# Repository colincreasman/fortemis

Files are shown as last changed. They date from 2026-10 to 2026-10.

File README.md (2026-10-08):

# Fortemis ZMK Config

ZMK config for the Fortemis keyboard (Forager+Totem+FerrisSweep)

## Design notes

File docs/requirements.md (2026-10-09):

# Fortemis: goals and requirements

Fortemis is a low-profile, wireless, split keyboard designed from scratch. It combines three boards
the owner already uses:

| Source board | What Fortemis takes from it |
|---|---|
| **Ferris Sweep** (Bling LP build by keebmaker) | Column layout: a tiny footprint and the steep column stagger, especially on the pinky |
| **TOTEM** by GEIST (and **Totemist**, ErgoMech's closed-source 36-key derivative) | Column splay angles only |
| **Forager** by carrefinho (sold by PandaKB) | Thumb-cluster placement and **everything else**: enclosed case, how the controller and battery are fitted, reset access, size, sturdiness, weight |

The name combines **For**ager, **Tem** (TOTEM/Totemist) and Ferr**is**.

This file records what the owner asked for. How each requirement is being met, and the decisions
behind that, are in [design-log.md](design-log.md).

## 1. Background

- The Ferris Sweep is the owner's favorite keyboard, because of its tiny footprint and the steep
  stagger on the pinky column.
- The owner's hands sweat a lot (hyperhidrosis). On the plateless Sweep, moisture has caused dead
  keys and switches keep falling out. The Forager's fully enclosed two-piece case has had neither
  problem: the top plate holds every switch in place, and the board is sealed in.
- The owner can easily press the Forager's reset button through a small print-in-place tab in the
  bottom case, and likes its size, sturdiness and light weight.
- The owner does not like the controller and battery arrangement on the Sweep or the TOTEM, or the
  loose wires visible on their current Sweep.
- The owner already has a few Seeed XIAO nRF52840 boards, the controller used in the Forager and
  TOTEM.
- All three of the owner's boards run ZMK with nearly the same keymap: QWERTY with home-row mods,
  and thumb keys Enter | Shift-Tab | NUM-Space | Backspace.

## 2. Tooling and deliverables

| ID | Requirement | Priority |
|---|---|---|
| T1 | Design the board with the free, open-source, beginner-friendly keyboard PCB tool from Ben Vallack's video. That tool is **Ergogen** ([video](https://www.youtube.com/watch?v=M_VuXVErD6E)). | MUST |
| T2 | Produce PCB design files (KiCad), case **STL** files, and everything else needed to build the board from scratch: fabrication outputs, parts list, firmware and build instructions. | MUST |
| T3 | Keep everything in this repository. | MUST |
| T4 | Write down the goals and requirements (this file), and keep a running record of the design process as work goes on ([design-log.md](design-log.md)). | MUST |

## 3. Layout

| ID | Requirement | Priority |
|---|---|---|
| L1 | **Column stagger** is the same as the Ferris Sweep's. | MUST |
| L1b | Make the stagger of the **4th and 5th columns** 10–20 % steeper, without straying far from the Sweep. | BONUS |
| L2 | **Column splay** uses the TOTEM's horizontal splay angles for each column, and nothing else. The stagger still follows L1. Owner's description: "barely perceptible between the first/second/third columns, getting wider toward the pinky column". | MUST |
| L3 | **Thumb cluster** has the same position (distance and angle) relative to the rest of the keyboard as the Forager's. | MUST |
| L4 | 34 keys: 3×5 plus 2 thumbs per half. Adding a 3rd thumb key per half (36 keys) is a bonus, but only if it doesn't enlarge the footprint or add PCB requirements. "Don't sweat it." | MUST (34) / BONUS (36) |
| L5 | Keys are as close together as **Choc keycaps** allow (Choc spacing). Fitting MX keycaps is not a goal. | MUST |

## 4. Electronics

| ID | Requirement | Priority |
|---|---|---|
| E1 | The controller is a **Seeed XIAO nRF52840**, like the Forager and TOTEM. It may be soldered straight to the PCB; no socket is needed. | SHOULD (preference) |
| E2 | **Wireless**, with a battery in each half. Copy how the Forager fits its XIAO and battery. | MUST |
| E3 | **Hot-swap sockets** for Kailh **Choc v1** switches. | MUST |
| E3b | Also accept **Choc v2** switches, as the Toucan2 does. | BONUS (big) |
| E4 | **Diodeless** like the Sweep is strongly wanted. If only a nice!nano can do diodeless, and only at 34 keys, use the nice!nano with 2 thumb keys per half. The exception is if that would break the Forager case's physical dimensions, which take priority. | SHOULD (strong) |
| E5 | A **power switch** and a **reset switch** on **each half**. The power switch must not be tiny like the Sweep's. TOTEM-sized switches are acceptable. | MUST |

## 5. Case and looks

| ID | Requirement | Priority |
|---|---|---|
| C1 | The case and everything else follow the **Forager**: a fully enclosed two-piece case, a top plate that holds the switches, reset access through a tab in the bottom case, the same size class, sturdy and light. | MUST (top priority) |
| C2 | No loose wires visible from outside. Everything sits inside the case, as on the Forager. | MUST |
| C3 | If the PCB makes any Forager feature impossible, **stop and tell the owner** so they can decide. | MUST (process) |

## 6. How ambiguous points were read

These readings were made without asking the owner. Each one is a single setting in the design, so
it is easy to change.

1. **"4th and 5th column" means the ring and pinky columns.** The owner numbered the TOTEM's columns
   from the inner side ("first/second/third … toward the pinky"). Counting that way also matches
   finger numbering (ring = 4, pinky = 5) and the owner's liking for a steep pinky stagger.
2. **Totemist splay means TOTEM splay.** Totemist has no public hardware files, and the owner said
   to use TOTEM. TOTEM's PCB has the inner, index and middle columns exactly parallel (0°), the
   ring column at 4° and the pinky column at 10°. The "barely perceptible" angle the owner sees is
   the ring column's 4°.
3. **Forager power switch.** The Forager has no power switch. It relies on ZMK's sleep mode, and its
   reset is the XIAO's own button pressed through the case lever. E5 is met by adding a power
   switch that is large enough to use with a finger, and by keeping the Forager's reset lever.
4. **Thumb position relative to the keyboard** is measured from the bottom key of the inner index
   column, the nearest key. That keeps the same gap and angle between the thumbs and the main keys
   as on the Forager.

## 7. Acceptance criteria

- The Ergogen config in `ergogen/` regenerates the layout, outlines and PCB.
- Layout: stagger matches the Sweep, with L1b applied to ring and pinky. Column angles are
  0/0/0/4/10° from the inner column outward. Thumbs sit relative to the inner column exactly as on
  the Forager. No Choc keycaps (17.5 × 16.5 mm) overlap.
- PCB: routed, passes KiCad DRC with no errors, and has Gerber, drill, BOM and placement outputs
  ready for ordering. Choc v1 hot-swap is required and v2 is supported if possible. Diodeless if
  possible. Power switch on each half. Reset reachable as on the Forager.
- Case: two-piece enclosed STL per half (top plate and base), built to the Forager's dimensions
  (8.4 mm stack, 2.2 mm top plate, 6.2 mm base). It includes the USB-C opening, reset lever, LED
  light pipe, power-switch opening and screw bosses, with no wires showing.
- Docs: parts list with links, build guide, and firmware (ZMK shield) for the chosen controller.

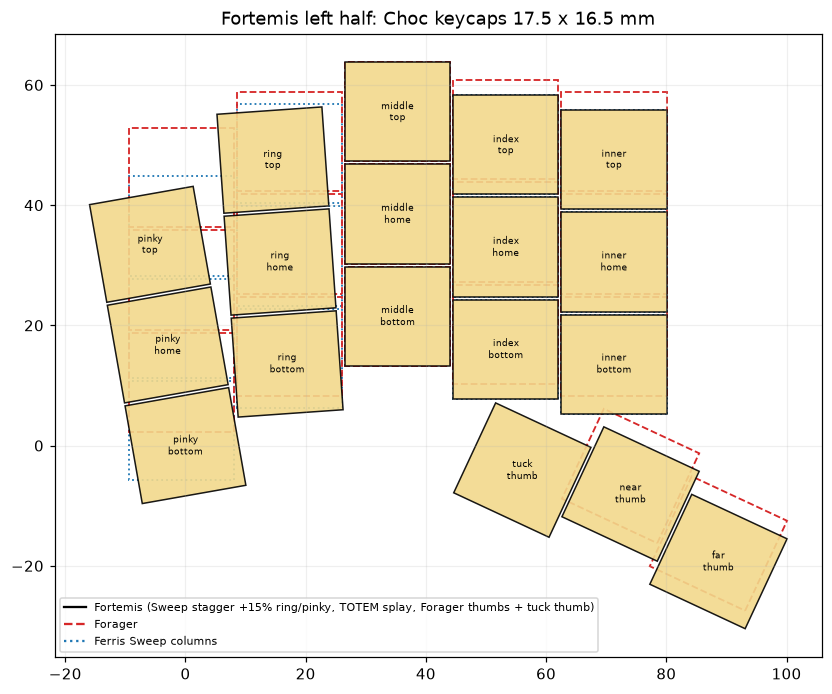
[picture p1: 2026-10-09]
docs/img/layout_compare.png

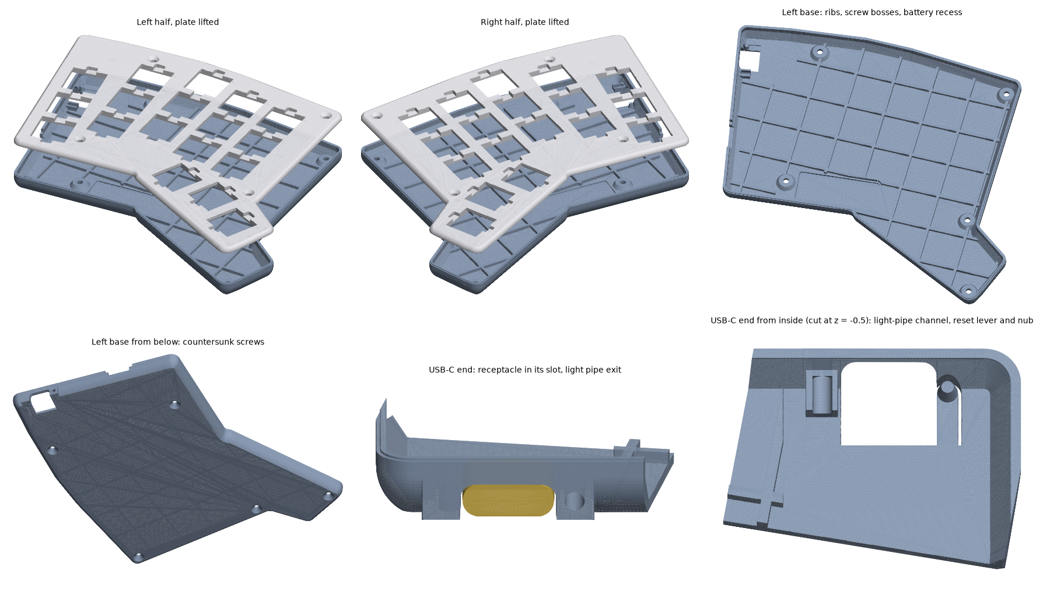
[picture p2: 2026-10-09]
docs/img/case.png

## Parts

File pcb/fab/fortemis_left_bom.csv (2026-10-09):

Comment | Designator | Footprint | LCSC Part #
Kailh Choc v1 hot-swap socket | S1,S2,S3,S4,S5,S6,S7,S8,S9,S10,S11,S12,S13,S14,S15,S16,S17,S18 | CPG135001S30 | C5333465
M2 SMD nut, 2 mm | NUT1,NUT2,NUT3,NUT4,NUT5 | SMTSO2020MTJ | C2916384
SPDT slide switch | PWR1 | MSK12C02 | C431540

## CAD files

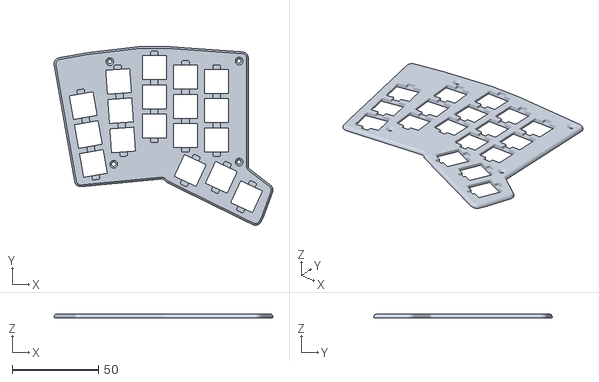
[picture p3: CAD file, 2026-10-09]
case/fortemis_left_top.stl
126.8 x 103.4 x 2.20

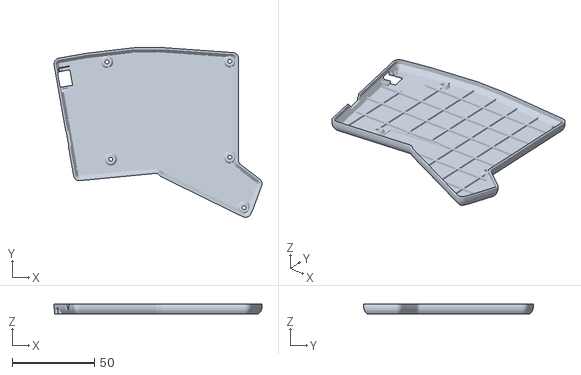
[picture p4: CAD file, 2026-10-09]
case/fortemis_left_base.stl
126.8 x 103.4 x 6.20

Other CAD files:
case/fortemis_right_top.stl
case/fortemis_right_base.stl

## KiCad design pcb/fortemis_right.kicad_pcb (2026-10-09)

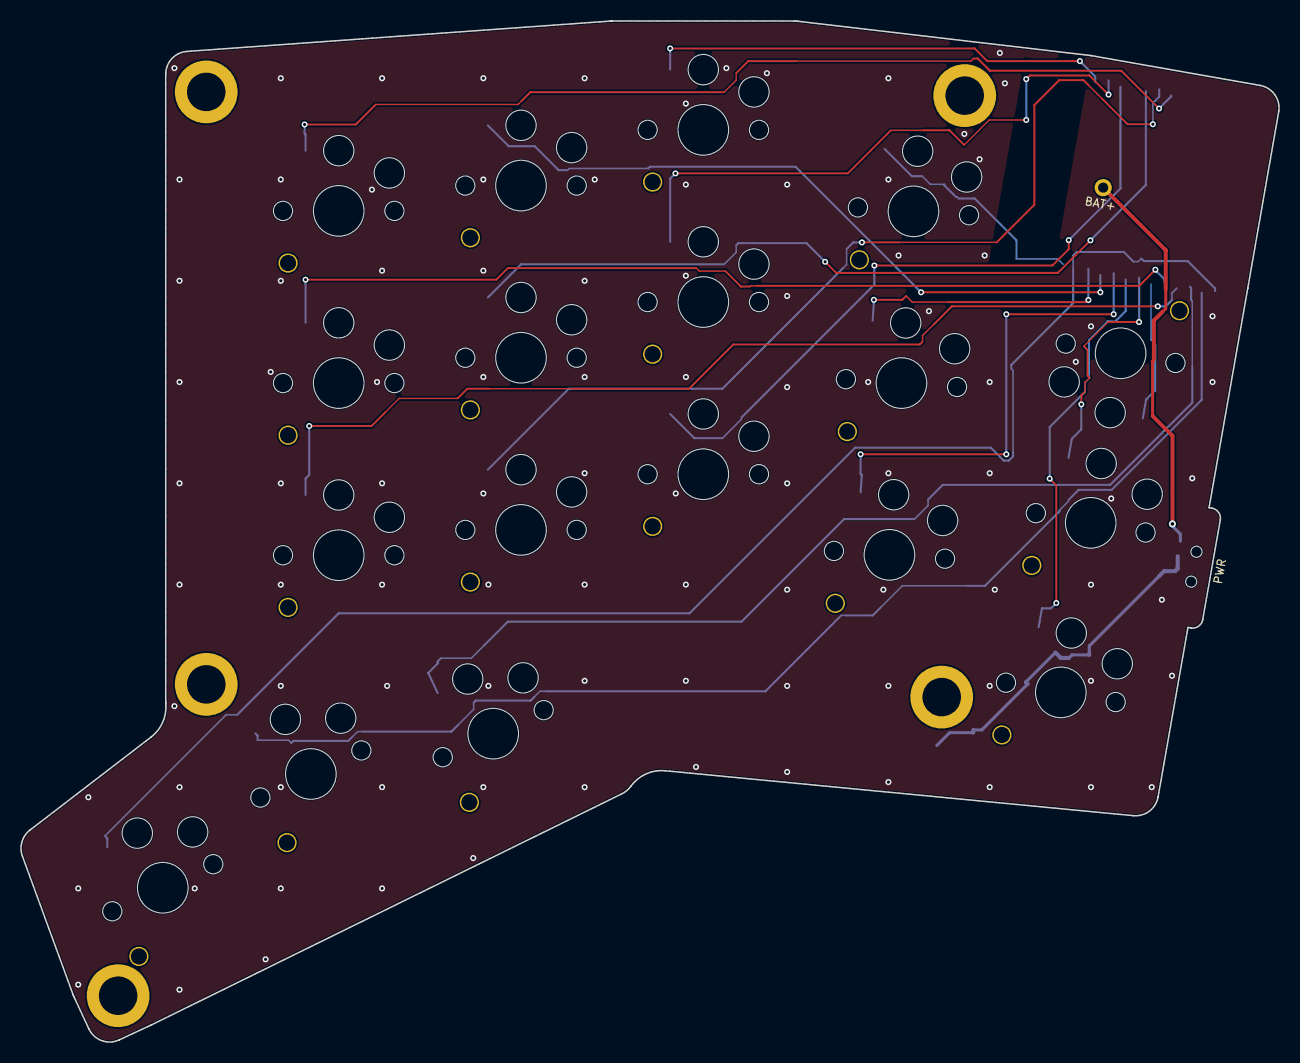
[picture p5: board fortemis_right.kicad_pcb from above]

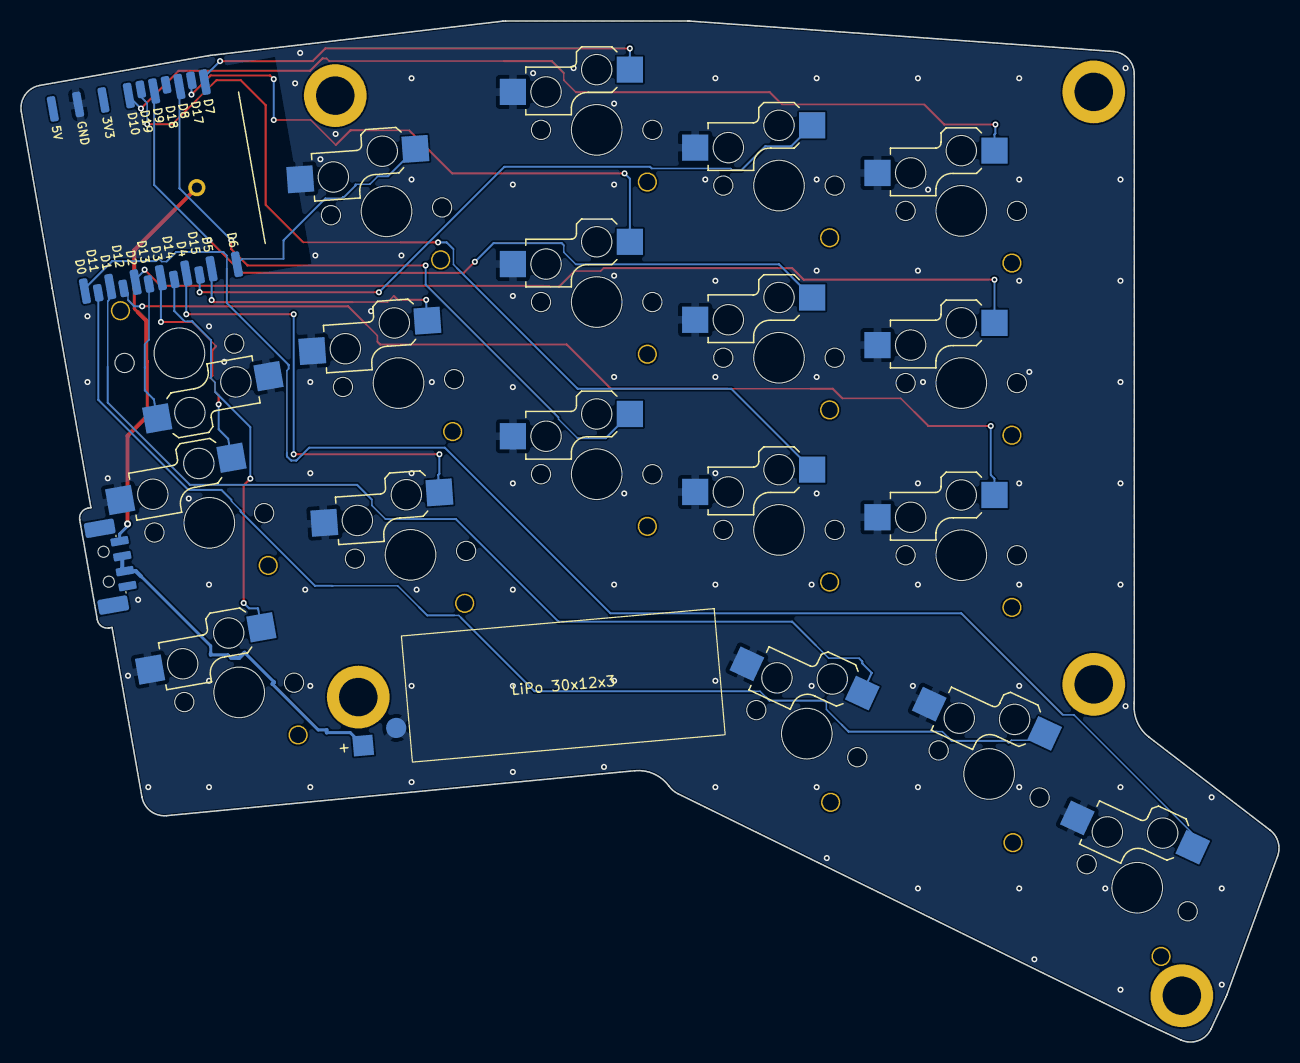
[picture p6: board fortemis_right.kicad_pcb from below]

Board: 2 copper layers, 124.2 x 100.8 mm, 26 parts (26 on the bottom side), 21 nets.

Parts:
BT1: LiPo 301230; battery_lipo_pads
MCU1: XIAO nRF52840 Plus; mcu_xiao_nrf52840_plus
NUT1, NUT2, NUT3, NUT4, NUT5: SMTSO2020MTJ; nut_smd_m2
PWR1: MSK12C02; power_switch_msk12c02_side
S1, S2, S3, S4, S5, S6, S7, S8, S9, S10, S11, S12, S13, S14, S15, S16, S17, S18: switch_choc_v1_v2

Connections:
BAT_P: MCU1.BAT+, PWR1.1
BAT_RAW: BT1.1, PWR1.2
D0: MCU1.D0, S17.1
D1: MCU1.D1, S15.1
D2: MCU1.D2, S13.1
D3: MCU1.D3, S2.1
D4: MCU1.D4, S3.1
D5: MCU1.D5, S4.1
D6: MCU1.D6, S5.1
D7: MCU1.D7, S8.1
D8: MCU1.D8, S6.1
D9: MCU1.D9, S10.1
D10: MCU1.D10, S14.1
D11: MCU1.D11, S16.1
D12: MCU1.D12, S12.1
D13: MCU1.D13, S18.1
D14: MCU1.D14, S1.1
D15: MCU1.D15, S11.1
D17: MCU1.D17, S7.1
D19: MCU1.D19, S9.1
GND: BT1.2, MCU1.GND, S1.2, S2.2, S3.2, S4.2, S5.2, S6.2, S7.2, S8.2, S9.2, S10.2, S11.2, S12.2, S13.2, S14.2, S15.2, S16.2, S17.2, S18.2

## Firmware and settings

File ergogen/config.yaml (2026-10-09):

# Fortemis: Ferris Sweep stagger + TOTEM splay + Forager thumbs. Ergogen 4.2.1.
# Rebuild: npx --yes ergogen@4.2.1 ergogen -o ergogen/output   (from repo root)
# Paste into https://ergogen.ceoloide.com to edit it visually.
meta:
  engine: 4.2.1
  name: fortemis
  version: 0.3.0
  author: colincreasman

units:
  kx: 18            # Choc spacing (requirement L5)
  ky: 17
  # Column stagger along each column's axis, solved by tools/check_layout.py so the home keys land
  # where the Ferris Sweep's do, with ring/pinky 15% steeper (decision D1).
  ring_stagger: 7.3170
  pinky_stagger: 11.4360
  index_drop: 5.5   # Sweep: index 5.5 mm below middle
  inner_drop: 2.5   # Sweep: inner 8 mm below middle = 2.5 below index
  # TOTEM splay pivots, relative to the bottom key of the column being rotated (decision D2)
  ring_pivot_y: -10.2303
  middle_pivot_y: -13.1231
  # Board edge and case (Forager): PCB edge 2.25 mm outside the key grid, case wall 1.3 mm outside that
  edge: 2.25
  case_ext: 1.3
  # XIAO nRF52840 Plus centre, in the pinky-top key's frame. The Forager uses (-0.5, 12); ours sits
  # 4.8 mm higher so its pads clear the pinky-top switch's Choc v2 centre hole and corner leg.
  xiao_x: -0.5
  xiao_y: 16.8
  xiao_l: 20.96     # module size: USB-C to antenna
  xiao_w: 17.78     # castellated edge to castellated edge
  # Extra board margin along the castellated edges: the pads reach 1.5 mm past the module, so the
  # plain `edge` margin leaves them 0.75 mm from the PCB edge. A 0.2 mm trace between them and the
  # 0.3 mm copper-to-edge limit would have only 0.05 mm to spare. 0.5 mm more leaves 1.25 mm.
  xiao_margin: 0.5
  usb_inset: 0.25   # USB-C end of the module inside the PCB edge (Forager)
  # Power switch tab: tab_w wide, from the case's outer surface tab_d into the board
  tab_w: 12
  tab_d: 3.35
  nut_box: 3.5      # 6.2 mm nut pad - 2 * (edge - 0.9)
  bat_l: 31         # area kept for the 301230 LiPo (30 x 12 x 3 mm cell plus tolerance)
  bat_w: 12.5

points:
  zones:
    matrix:
      anchor:
        rotate: 10                # pinky column angle (TOTEM)
      key:
        spread: kx
        padding: ky
        width: kx
        height: ky
      columns:
        # pins: XIAO pin wired to each key (left half; mirror.pin = right half). Diodeless: each
        # key goes straight from its pin to GND (decision D5).
        pinky:
          rows:
            bottom: {pin: D9, mirror.pin: D14}
            home: {pin: D19, mirror.pin: D3}
            top: {pin: D10, mirror.pin: D13}
        ring:
          key:
            stagger: pinky_stagger    # ring sits this far above pinky
            splay: -6                 # 10 -> 4 deg
            origin: [-kx/2, ring_pivot_y]
          rows:
            bottom: {pin: D18, mirror.pin: D4}
            home: {pin: D8, mirror.pin: D5}
            top: {pin: D17, mirror.pin: D6}
        middle:
          key:
            stagger: ring_stagger
            splay: -4                 # 4 -> 0 deg
            origin: [-kx/2, middle_pivot_y]
          rows:
            bottom: {pin: D5, mirror.pin: D8}
            home: {pin: D6, mirror.pin: D17}
            top: {pin: D7, mirror.pin: D7}
        index:
          key.stagger: -index_drop
          rows:
            bottom: {pin: D3, mirror.pin: D19}
            home: {pin: D14, mirror.pin: D9}
            # right: D15, not D18. The right XIAO's D18 pad sits in the row along the board edge,
            # boxed in by D8 and D9, and Freerouting can't get a trace out of it.
            top: {pin: D4, mirror.pin: D15}
        inner:
          key.stagger: -inner_drop
          rows:
            bottom: {pin: D12, mirror.pin: D12}
            home: {pin: D2, mirror.pin: D2}
            top: {pin: D13, mirror.pin: D10}
      rows:
        bottom:
        home:
        top:
    thumbs:
      # Forager: near thumb = inner bottom key + (2.749, -21.6), thumbs rotated 25 deg clockwise,
      # far thumb = 18 mm along and 4 mm down in the rotated frame (decision D3).
      # Bonus 3rd "tuck" thumb mirrors the far one on the inner side (decision D7); the zone starts
      # there, so the anchor steps back 18 mm along and 4 mm down from the near thumb.
      anchor:
        - ref: matrix_inner_bottom
          shift: [2.749, -21.6]
          rotate: -25
        - shift: [-kx, -4]
      key:
        width: kx
        height: ky
        spread: kx
      columns:
        tuck:
          key: {pin: D1, mirror.pin: D1}
        near:
          key: {stagger: 4, pin: D11, mirror.pin: D11}
        far:
          key: {stagger: -4, pin: D0, mirror.pin: D0}
      rows:
        thumb:
    mcu:
      # XIAO nRF52840 Plus, face down on the back above the pinky column (Forager, decision D4).
      # width/height only shape the board outline: the hull box is shortened so the USB-C end
      # lands usb_inset inside the PCB edge.
      anchor:
        ref: matrix_pinky_top
        shift: [xiao_x, xiao_y]
      key:
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

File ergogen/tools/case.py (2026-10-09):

#!/usr/bin/env python3
"""Generate the Fortemis case, a top plate and a base for each half, around the routed PCBs.

  python3 ergogen/tools/case.py                  # both halves -> case/*.stl and docs/img/case.png
  python3 ergogen/tools/case.py fortemis_left    # one half

The board outline, switches, nuts, XIAO, power switch and battery come from pcb/<board>.kicad_pcb
through KiCad's bundled Python (pcb_kicad.py geom), so the case follows the PCB. The dimensions copy
the Forager case (docs/design-log.md). Each part is checked against simple models of the components,
and the script fails if anything overlaps.

Needs KiCad 10 and `pip install -r ergogen/tools/requirements.txt`.

Frame: mm; x right, y away from the typist (KiCad's y flipped), z up; z = 0 is the PCB's bottom face.
"""
import json, pathlib, re, subprocess, sys, tempfile

import manifold3d as m3d
import numpy as np
from shapely import affinity
from shapely.geometry import Point, Polygon, box
from shapely.geometry.polygon import orient
from shapely.ops import unary_union

sys.path.insert(0, str(pathlib.Path(__file__).parent))
from pcb import BOARDS, KICAD_PY, PCB, ROOT  # noqa: E402

OUT = ROOT / 'case'
IMG = ROOT / 'docs' / 'img' / 'case.png'
CONFIG = ROOT / 'ergogen' / 'config.yaml'
SEGS = 48                       # segments per circle

# Stack: base bottom, floor top, PCB bottom (0), PCB top = base rim, plate top. 8.4 mm overall.
Z_BOTTOM, Z_FLOOR, Z_PCB, Z_TOP = -4.6, -3.6, 1.6, 3.8
EDGE = 1.3                      # case outline = PCB outline (without the switch tab) + EDGE
GAP = 0.3                       # PCB edge to the base's inner wall
TAPER_Z, TAPER = -0.6, 2.0      # below TAPER_Z the inner wall leans TAPER inward by the floor
SCREW_D = 2.4                   # M2 clearance
NUT_BOTTOM = -2.0               # SMD nuts hang 2.0 below the PCB

# Top plate
CUT, CUT_R = 13.9, 0.0          # switch cutout, square-cornered like Forager's, rotated with the key
CLIP = 1.0                      # 45 deg chamfer under the E/W sides: 1.2 mm ledge for the clips
GROOVE_W, GROOVE_L, GROOVE_Z, GROOVE_R = 4.4, 2.55, 2.3, 0.7   # switch-puller grooves N and S
TOP_CSK_D, TOP_CSK_DEPTH = 4.5, 1.05
POCKET_D, POCKET_DEPTH = 3.0, 0.6   # under through-hole solder joints (XIAO BAT+)
MIN_CSK_WALL = 0.8              # a nut gets a top screw only this far from cutouts and grooves

# Base
BOSS_R0, BOSS_R1, BOSS_TOP = 3.78, 2.78, -2.1
BOT_CSK_D, BOT_CSK_DEPTH = 5.0, 1.3
RIB_W, RIB_TOP, RIB_PITCH, RIB_CLEAR = 1.0, -2.4, 15.0, 1.0
BAT_RECESS, BAT_CELL = 0.4, (30.0, 12.0, 3.3)
PANEL_V = 8.4                   # outer wall flat and vertical for this far either side of the USB-C

# XIAO frame: u from the USB-C end of the module inward, v toward the D0..D6 pad row.
XIAO_L, XIAO_W = 20.96, 17.78
USB_SLOT = (4.72, -0.95, 1.5, 2.0)          # half width, top z, top corner radius, inner end u
USB_C = (8.94, 3.25, -1.56, 6.5)            # receptacle shell (stadium): width, height, u range
USB_HOLE = (4.75, 7.43)                     # floor opening: half width, inner end u
LEVER = (1.88, 7.43, 4.75, 6.75, 0.4)       # tip centre u, root u, v range, slot width
LEVER_CLEAR_Z = -0.9
NUB = (1.0, 0.6, -2.0)                      # cone radius at floor, at top, top z
PIPE = (-6.513, -2.7, 1.95, 4.43)           # light pipe bore: v, z, diameter, inner end u
PIPE_BLOCK = (-8.11, -5.04, -1.75, 0.85)    # filament channel: v range, top z, open from u

# Power switch frame: t along the switch's front face, n outward; notch through the base wall
NOTCH = ((6.3, 0.0, Z_PCB), (4.9, -1.8, 0.0))   # (half width, z0, z1): PCB tab, switch body
NOTCH_N = -3.5


def unit(v):
    v = np.asarray(v, float)
    return v / np.linalg.norm(v)


def xy(p):
    return np.array([p['x'], p['y']])


class Frame:
    """Local 2D coordinates (a, b) -> world origin + a * ea + b * eb."""

    def __init__(self, origin, ea, eb=None):
        self.o, self.ea = np.asarray(origin, float), unit(ea)
        self.eb = unit(eb) if eb is not None else np.array([-self.ea[1], self.ea[0]])

    def __call__(self, a, b):
        return self.o + a * self.ea + b * self.eb

    def local(self, p):
        d = np.asarray(p, float) - self.o
        return np.array([d @ self.ea, d @ self.eb])

    def geom(self, g):
        return affinity.affine_transform(g, [self.ea[0], self.eb[0], self.ea[1], self.eb[1], *self.o])


def rrect(w, h, r, cx=0.0, cy=0.0):
    b = box(cx - w / 2 + r, cy - h / 2 + r, cx + w / 2 - r, cy + h / 2 - r)
    return b.buffer(r, quad_segs=SEGS // 4) if r > 0 else b


def disc(c, r):
    return Point(*c).buffer(r, quad_segs=SEGS // 4)


def section(g):
    rings = []
    for p in getattr(g, 'geoms', [g]):
        if not p.is_empty:
            rings += [np.asarray(r.coords)[:-1] for r in [p.exterior, *p.interiors]]
    return m3d.CrossSection(rings, m3d.FillRule.EvenOdd)


def prism(g, z0, z1):
    return section(g).extrude(z1 - z0).translate([0, 0, z0])


def cone(c, r0, z0, r1, z1):
    return m3d.Manifold.cylinder(z1 - z0, r0, r1, SEGS).translate([c[0], c[1], z0])


def union(solids):
    return m3d.Manifold.batch_boolean(list(solids), m3d.OpType.Add)


def smooth(poly, r):
    """Round every outside corner to at least r (opening). The outline's arcs come polygonised from
    KiCad and buffering adds tiny joins along them, which would fold over when loft() insets them."""
    out = poly.buffer(-r, quad_segs=16).buffer(r, quad_segs=16).simplify(0.001)
    assert out.geom_type == 'Polygon' and poly.hausdorff_distance(out) < 0.3
    return out


def loft(poly, levels):
    """Solid whose cross-section at each (z, d) level is `poly` inset by d (levels bottom to top).
    Vertices move along their miters: only valid for insets below the smallest outside radius."""
    p = np.asarray(orient(poly, 1.0).exterior.coords)[:-1]
    e = np.roll(p, -1, 0) - p
    out = np.column_stack([e[:, 1], -e[:, 0]]) / np.linalg.norm(e, axis=1)[:, None]
    a, b = np.roll(out, 1, 0), out
    miter = (a + b) / (1 + (a * b).sum(1))[:, None]
    rings = [p - d * miter for _, d in levels]
    for (z, d), r in zip(levels, rings):
        assert Polygon(r).is_valid, f'outline inset by {d} at z={z} self-intersects'
    n, i = len(p), np.arange(len(p))
    j = np.roll(i, -1)
    verts = np.vstack([np.column_stack([r, np.full(n, z)]) for r, (z, _) in zip(rings, levels)])
    tris = [m3d.triangulate([rings[0]])[:, ::-1], m3d.triangulate([rings[-1]]) + (len(levels) - 1) * n]
    for k in range(len(levels) - 1):
        lo, hi = k * n, (k + 1) * n
        tris += [np.column_stack([lo + i, lo + j, hi + j]), np.column_stack([lo + i, hi + j, hi + i])]
    solid = m3d.Manifold(m3d.Mesh(vert_properties=verts.astype(np.float32),
                                  tri_verts=np.vstack(tris).astype(np.uint32)))
    assert solid.status() == m3d.Error.NoError, solid.status()
    return solid


def arc(r, z_tangent, z_end, steps=16):
    """(z, inset) along a round of radius r that is tangent to the vertical wall at z_tangent."""
    t = np.linspace(0, np.arcsin(min(1.0, abs(z_end - z_tangent) / r)), steps)
    return [(z_tangent + np.sign(z_end - z_tangent) * r * np.sin(a), r * (1 - np.cos(a))) for a in t]


TOP_EDGE = [(Z_PCB, 0.35), (Z_PCB + 0.35, 0.0)] + arc(2.08, 2.0, Z_TOP)        # 0.35 chamfer, round
BASE_EDGE = arc(5.39, -0.182, Z_BOTTOM)[::-1] + [(1.4, 0.0), (1.4, 0.4), (Z_PCB, 0.4)]  # round, reveal


def load(board):
    with tempfile.TemporaryDirectory() as d:
        out = pathlib.Path(d) / 'geom.json'
        r = subprocess.run([KICAD_PY, str(pathlib.Path(__file__).with_name('pcb_kicad.py')), 'geom',
                            str(PCB / f'{board}.kicad_pcb'), str(out)], capture_output=True, text=True)
        if r.returncode:
            sys.exit(r.stdout + r.stderr)
        return json.loads(out.read_text())


def config_value(name):
    return float(re.search(rf'^\s*{name}:\s*([\d.]+)', CONFIG.read_text(), re.M).group(1))


class Half:
    def __init__(self, board):
        self.name = board
        g = load(board)
        flip = lambda pts: [(x, -y) for x, y in pts]
        o = g['outline'][0]
        self.board = Polygon(flip(o['outer']), [flip(h) for h in o['holes']])
        fps = g['footprints']
        for f in fps:
            f['y'] = -f['y']
            for p in f['pads']:
                p['y'] = -p['y']
        kind = lambda prefix: [f for f in fps if f['lib'].startswith(prefix)]
        self.switches = kind('switch_')
        self.keys = [self.key_frame(f) for f in self.switches]
        self.nuts = [np.array([f['x'], f['y']]) for f in kind('nut_')]
        self.mcu = self.mcu_frame(kind('mcu_')[0])
        self.pwr = self.power_frame(kind('power_switch')[0])
        bat = kind('battery')[0]
        rot = np.radians(bat['rot'])
        self.bat = Frame(xy(bat), [np.cos(rot), np.sin(rot)])
        self.bat_area = (config_value('bat_l'), config_value('bat_w'))
        self.bat_pads = [xy(p) for p in bat['pads']]
        others = [f for f in fps if f not in self.switches and not f['lib'].startswith('nut_')]
        self.solder = [(xy(p), max(POCKET_D, p['w'] + 1.3)) for f in others for p in f['pads']
                       if p['kind'] == 'th' and p['front']]
        self.notab = self.remove_tab()
        # PCB corners are r2.25: just round the polygonised arcs
        self.outline = smooth(self.notab.buffer(EDGE, quad_segs=SEGS // 4), 2.25 + EDGE + 0.05)
        self.cavity = smooth(self.notab.buffer(GAP, quad_segs=SEGS // 4), 2.25 + GAP + 0.05)
        self.cutouts = unary_union([k.geom(rrect(CUT, CUT, CUT_R)) for k in self.keys]
                                   + [k.geom(g) for k in self.keys for g in self.grooves()])
        self.top_screws = [c for c in self.nuts
                           if Point(*c).distance(self.cutouts) >= TOP_CSK_D / 2 + MIN_CSK_WALL]

    @staticmethod
    def key_frame(f):
        holes = [p for p in f['pads'] if p['kind'] == 'npth']
        posts = [xy(p) for p in holes if abs(p['drill'][0] - 1.9) < 0.05]
        return Frame(xy(max(holes, key=lambda p: p['drill'][0])), posts[1] - posts[0])

    @staticmethod
    def mcu_frame(f):
        pad = {p['name']: xy(p) for p in f['pads']}
        out = unit(pad['D0'] + pad['5V'] - pad['D6'] - pad['D7'])
        across = pad['D0'] - pad['5V']
        centre = (pad['D0'] + pad['5V'] + pad['D6'] + pad['D7']) / 4
        return Frame(centre + out * XIAO_L / 2, -out, across - (across @ out) * out)

    @staticmethod
    def power_frame(f):
        pins = [xy(p) for p in f['pads'] if p['name'] in ('1', '2', '3')]
        n = unit(xy(f) - np.mean(pins, 0))
        return Frame(xy(f), [n[1], -n[0]], n)

    def remove_tab(self):
        """The board without the power-switch tab, which ends flush with the case's outer wall."""
        tn = np.array([self.pwr.local(p) for p in self.board.exterior.coords])
        side = tn[(np.abs(tn[:, 0]) > 12) & (np.abs(tn[:, 0]) < 25)]
        edge = side[:, 1].max()
        tab_end = tn[np.abs(tn[:, 0]) < 6.5][:, 1].max()
        assert abs(tab_end - edge - EDGE) < 0.05, f'switch tab should end {EDGE} past the board edge'
        notab = self.board.difference(self.pwr.geom(box(-25, edge, 25, edge + 10)))
        assert 0 < self.board.area - notab.area < 30
        return notab

    @staticmethod
    def grooves():
        length = GROOVE_L + 1.0
        c = CUT / 2 + GROOVE_L - length / 2
        return [rrect(GROOVE_W, length, GROOVE_R, 0, c), rrect(GROOVE_W, length, GROOVE_R, 0, -c)]

    # ---------------------------------------------------------------- top plate
    def switch_cut(self, k):
        corners = lambda w, z: [[*k(a, b), z] for a, b in np.asarray(rrect(w, CUT, CUT_R).exterior.coords)]
        z0 = Z_PCB - 0.1
        chamfer = m3d.Manifold.hull_points(np.array(corners(CUT + 2 * (CLIP + 0.1), z0)
                                                    + corners(CUT, Z_PCB + CLIP)))
        straight = prism(k.geom(rrect(CUT, CUT, CUT_R)), Z_PCB + CLIP - 0.01, Z_TOP + 1)
        grooves = prism(unary_union([k.geom(g) for g in self.grooves()]), GROOVE_Z, Z_TOP + 1)
        return chamfer + straight + grooves

    def top(self):
        cuts = [self.switch_cut(k) for k in self.keys]
        for c in self.top_screws:
            cuts += [cone(c, SCREW_D / 2, Z_PCB - 1, SCREW_D / 2, Z_TOP + 1),
                     cone(c, SCREW_D / 2, Z_TOP - TOP_CSK_DEPTH, TOP_CSK_D / 2 + 0.1, Z_TOP + 0.1)]
        cuts += [cone(c, d / 2, Z_PCB - 1, d / 2, Z_PCB + POCKET_DEPTH) for c, d in self.solder]
        return loft(self.outline, TOP_EDGE) - union(cuts)

    # ---------------------------------------------------------------- base
    def keepouts(self):
        """Floor areas the ribs stay out of."""
        u = self.mcu
        return unary_union([
            self.bat.geom(rrect(*self.bat_area, 1.0)),
            *[disc(p, 2.5) for p in self.bat_pads],
            u.geom(box(-5, -XIAO_W / 2 - 0.5, XIAO_L, XIAO_W / 2 + 0.5)),
            self.pwr.geom(box(-NOTCH[1][0], NOTCH_N, NOTCH[1][0], 5)),
        ]).buffer(RIB_CLEAR)

    def ribs(self):
        floor = self.notab.buffer(GAP - TAPER + 0.4)          # 0.4 into the leaning wall
        x0, y0, x1, y1 = floor.bounds
        cx, cy = self.notab.centroid.x, self.notab.centroid.y
        xs = cx + RIB_PITCH * np.arange(-np.ceil((cx - x0) / RIB_PITCH), np.ceil((x1 - cx) / RIB_PITCH) + 1)
        ys = cy + RIB_PITCH * np.arange(-np.ceil((cy - y0) / RIB_PITCH), np.ceil((y1 - cy) / RIB_PITCH) + 1)
        grid = unary_union([box(x - RIB_W / 2, y0, x + RIB_W / 2, y1) for x in xs]
                           + [box(x0, y - RIB_W / 2, x1, y + RIB_W / 2) for y in ys])
        return grid.intersection(floor).difference(self.keepouts())

    def along_u(self, prof, u0, u1):
        """Extrude a profile drawn in the XIAO's (v, z) plane along u from u0 to u1."""
        ea, eb, o = self.mcu.ea, self.mcu.eb, self.mcu(u0, 0)
        m = np.array([[eb[0], 0, ea[0], o[0]], [eb[1], 0, ea[1], o[1]], [0, 1, 0, 0]])
        return section(prof).extrude(u1 - u0).transform(m)

    def usb_slot(self):
        w, top, r, end = USB_SLOT
        prof = unary_union([box(-w, Z_BOTTOM - 1, w, top - r), box(-w + r, Z_BOTTOM - 1, w - r, top),
                            disc((-w + r, top - r), r), disc((w - r, top - r), r)])
        return self.along_u(prof, -6, end)

    def lever(self):
        tip, root, v0, v1, slot = LEVER
        vc = (v0 + v1) / 2
        arm = unary_union([box(tip, v0, root, v1), disc((tip, vc), (v1 - v0) / 2)])
        around = unary_union([box(tip, v0 - 1, root, v1 + slot), disc((tip, vc), (v1 - v0) / 2 + slot)])
        return self.mcu.geom(around.difference(arm)), self.mcu.geom(around), self.mcu(tip, vc)

    def base(self):
        u = self.mcu
        body = loft(self.outline, BASE_EDGE)
        body += prism(u.geom(box(-6, -PANEL_V, 3, PANEL_V)).intersection(self.outline), Z_BOTTOM, 1.0)
        body -= loft(self.cavity, [(Z_FLOOR, TAPER), (TAPER_Z, 0.0), (Z_PCB + 1, 0.0)])
        pv, pz, pd, pend = PIPE
        bv0, bv1, btop, bopen = PIPE_BLOCK
        slope = (BOSS_R0 - BOSS_R1) / (BOSS_TOP - Z_FLOOR)
        body += union([cone(c, BOSS_R0 + 0.1 * slope, Z_FLOOR - 0.1, BOSS_R1, BOSS_TOP) for c in self.nuts]
                      + [prism(self.ribs(), Z_FLOOR - 0.1, RIB_TOP),
                         prism(u.geom(box(-1.0, bv0, pend, bv1)), Z_FLOOR - 0.1, btop)])

        slot, clear, tip = self.lever()
        bore = m3d.Manifold.cylinder(pend + 6, pd / 2, pd / 2, SEGS).rotate(
            [0, 90, np.degrees(np.arctan2(u.ea[1], u.ea[0]))]).translate([*u(-6, pv), pz])
        cuts = [self.usb_slot(),
                prism(u.geom(box(-6, -USB_HOLE[0], USB_HOLE[1], USB_HOLE[0])), Z_BOTTOM - 1, Z_FLOOR + 0.1),
                prism(slot, Z_BOTTOM - 1, Z_FLOOR + 0.05), prism(clear, Z_FLOOR, LEVER_CLEAR_Z),
                bore, prism(u.geom(box(bopen, pv - pd / 2, pend + 1, pv + pd / 2)), pz, btop + 0.5),
                prism(self.bat.geom(rrect(self.bat_area[0] + 0.5, self.bat_area[1] + 0.5, 1.0)),
                      Z_FLOOR - BAT_RECESS, Z_FLOOR + 0.1)]
        for w, z0, z1 in NOTCH:
            cuts.append(prism(self.pwr.geom(box(-w, NOTCH_N, w, 5)), z0, z1 + 0.1))
        for c in self.nuts:
            cuts += [cone(c, SCREW_D / 2, Z_BOTTOM - 1, SCREW_D / 2, NUT_BOTTOM + 0.1),
                     cone(c, BOT_CSK_D / 2 + 0.1, Z_BOTTOM - 0.1, SCREW_D / 2, Z_BOTTOM + BOT_CSK_DEPTH)]
        body -= union(cuts)
        r0, r1, ztop = NUB
        return body + cone(tip, r0, Z_FLOOR - 0.05, r1, ztop)

    # ---------------------------------------------------------------- checks
    def components(self):
        """Simplified solids for everything the case must clear."""
        u, s, parts = self.mcu, self.pwr, {}
        add = lambda k, solid: parts.setdefault(k, []).append(solid)
        add('PCB', prism(self.board, 0, Z_PCB))
        for k, f in zip(self.keys, self.switches):
            add('switch housing', prism(k.geom(box(-6.9, -6.9, 6.9, 6.9)), Z_PCB, Z_TOP))
            socket = [p for p in f['pads'] if p['kind'] == 'smd' or abs(p['drill'][0] - 3.0) < 0.05]
            hull = unary_union([disc(xy(p), max(p['w'], p['h']) / 2) for p in socket]).convex_hull
            add('hot-swap socket', prism(hull.buffer(0.5), -1.85, 0))
            for p in f['pads']:
                if p['kind'] != 'smd' and abs(p['drill'][0] - 3.0) > 0.05:
                    add('switch posts', cone(xy(p), p['drill'][0] / 2 + 0.2, -2.2, p['drill'][0] / 2 + 0.2, 0))
        for c in self.nuts:
            add('nuts', cone(c, 2.6, NUT_BOTTOM, 2.6, 0))
        add('XIAO', prism(u.geom(box(0, -XIAO_W / 2, XIAO_L, XIAO_W / 2)), -1.0, 0))
        add('XIAO', prism(u.geom(box(4.5, -XIAO_W / 2 + 0.5, XIAO_L, XIAO_W / 2 - 0.5)), -2.05, -1.0))
        add('XIAO', prism(u.geom(box(0.2, -6.5, 3.5, -5.0)), -1.6, -1.0))         # RGB and charge LEDs
        add('XIAO', prism(u.geom(box(0.3, 4.85, 3.5, 6.6)), -1.6, -1.0))          # reset button
        w, h, u0, u1 = USB_C
        add('USB-C receptacle', self.along_u(rrect(w, h, h / 2 - 0.02, 0, -1.0 - h / 2), u0, u1))
        add('power switch', prism(s.geom(box(-3.5, -2.7, 3.5, 0)), -1.5, 0))
        add('power switch', prism(s.geom(box(-4.6, -2.0, 4.6, -0.6)), -0.5, 0))
        add('power switch', prism(s.geom(box(-2.25, 0, 2.25, 1.5)), -1.2, -0.3))
        bl, bw, bh = BAT_CELL
        add('battery', prism(self.bat.geom(rrect(bl, bw, 0.5)), Z_FLOOR - BAT_RECESS + 0.01,
                             Z_FLOOR - BAT_RECESS + bh))
        for p in self.bat_pads:
            add('battery wires', cone(p, 1.5, -1.0, 1.5, 0))
        return {k: union(v) for k, v in parts.items()}

    def check(self, parts):
        comps, ok = self.components(), True
        for name, solid in parts.items():
            pieces = len(solid.decompose())
            x0, y0, z0, x1, y1, z1 = solid.bounding_box()
            print(f'  {name}: {solid.volume() / 1000:.1f} cm3, {x1 - x0:.1f} x {y1 - y0:.1f} x {z1 - z0:.1f} mm,'
                  f' {solid.num_tri()} triangles, genus {solid.genus()}, {pieces} piece(s)')
            ok &= pieces == 1 and solid.status() == m3d.Error.NoError
            gaps = []
            for cname, comp in comps.items():
                clash = (solid ^ comp).volume()
                if clash > 1e-3:
                    print(f'    CLASH with {cname}: {clash:.3f} mm3')
                    ok = False
                elif cname != 'PCB':
                    gaps.append(f'{cname} {solid.min_gap(comp, 2.0):.2f}')
            print('    min gap (mm): ' + ', '.join(gaps))
        inside = [k for k in comps if k not in ('PCB', 'switch housing', 'battery')]
        for k in inside:
            clash = (comps['battery'] ^ comps[k]).volume()
            if clash > 1e-3:
                print(f'    battery CLASH with {k}: {clash:.3f} mm3')
                ok = False
        print(f'  top screws at {len(self.top_screws)} of {len(self.nuts)} nuts; '
              f'{len(self.keys)} switches; checks {"passed" if ok else "FAILED"}')
        return ok


def write_stl(solid, path):
    mesh = solid.to_mesh()
    v = np.asarray(mesh.vert_properties)[:, :3].astype(np.float32)
    tri = v[np.asarray(mesh.tri_verts)]
    n = np.cross(tri[:, 1] - tri[:, 0], tri[:, 2] - tri[:, 0])
    n /= np.maximum(np.linalg.norm(n, axis=1, keepdims=True), 1e-12)
    rec = np.zeros(len(tri), dtype=[('n', '<f4', 3), ('v', '<f4', (3, 3)), ('attr', '<u2')])
    rec['n'], rec['v'] = n, tri
    with open(path, 'wb') as f:
        f.write(f'Fortemis {path.stem}'.encode().ljust(80, b' '))
        f.write(np.uint32(len(tri)).tobytes())
        f.write(rec.tobytes())


def look(elev, azim):
    e, a = np.radians(elev), np.radians(azim)
    return np.array([np.cos(e) * np.cos(a), np.cos(e) * np.sin(a), np.sin(e)])


def crop(solid, centre, r, z1=10.0):
    return solid ^ m3d.Manifold.cube([2 * r, 2 * r, z1 + 10]).translate([centre[0] - r, centre[1] - r, -10])
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

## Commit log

2026-10-09 Update .gitignore for ZMK module, KiCad and Python
2026-10-09 Vendor ceoloide Ergogen footprints at 36a24f5
2026-10-09 Add XIAO Plus, MSK12C02, nut and LiPo footprints
2026-10-09 Add `pcb.py` to build, route and export the PCBs
2026-10-09 Add routed PCBs for both halves
    [fortemis_left.kicad_pcb, fortemis_right.kicad_pcb]
2026-10-09 Add Gerber zips and JLCPCB BOM and placement files
    [fortemis_left_bom.csv, fortemis_right_bom.csv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]
2026-10-09 Add `case.py` and the printable case STLs
    [fortemis_left_base.stl, fortemis_left_top.stl, fortemis_right_base.stl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]
2026-10-09 Add Fortemis ZMK shield generated from the PCBs
2026-10-09 Move the thumb arc 15 mm past the Totemist's
2026-10-09 Route GND and re-route until DRC passes
2026-10-09 Rebuild PCBs and fab files for the new thumbs
2026-10-09 Rebuild the case for the new thumbs
2026-10-13 Move the enclosed case into `case/enclosed`
2026-10-13 Add the sandwich case generator and STLs
2026-10-13 Document the sandwich case (C4)
2026-10-28 Bias hold-taps toward hold to cut TAP misfires
